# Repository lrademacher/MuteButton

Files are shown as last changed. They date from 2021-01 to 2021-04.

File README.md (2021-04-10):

# MuteButton
A digispark based mute-button for attaching to PC.

See MuteButton for arduino project for the digispark.
See case for 3d models for a case using a LED and a arcade button.

The device looks like this:
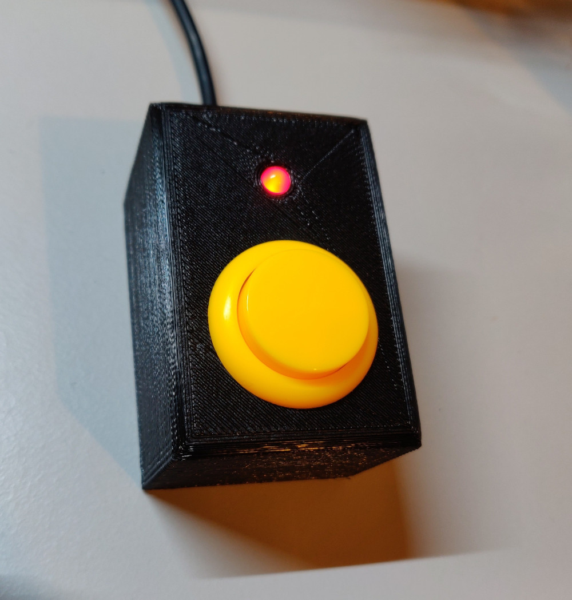
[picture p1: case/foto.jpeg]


## Operation
The device always starts in unmuted state (as there is no backchannel to read the mute information from the system).
When pushing the button, the configured mute command is sent to the PC as keyboard keystroke and the LED is switched on to show that the system is now muted.
When pushing the button again, the configured mute command is sent to the PC as keyboard keystroke and the LED is switched off to show that the system is now unmuted.
In muted state, you can keep the button pushed. On pressing the button, the system is unmuted and on releasing it, it is muted again. The button needs to be pushed for at least 500ms for this "push-to-talk" mode to be activated. The led blinks while this mode is active.

## Links
For a more detailed description see this blog post: https://lars-ra.blogspot.com/2021/04/mute-button-for-conference-calls.html

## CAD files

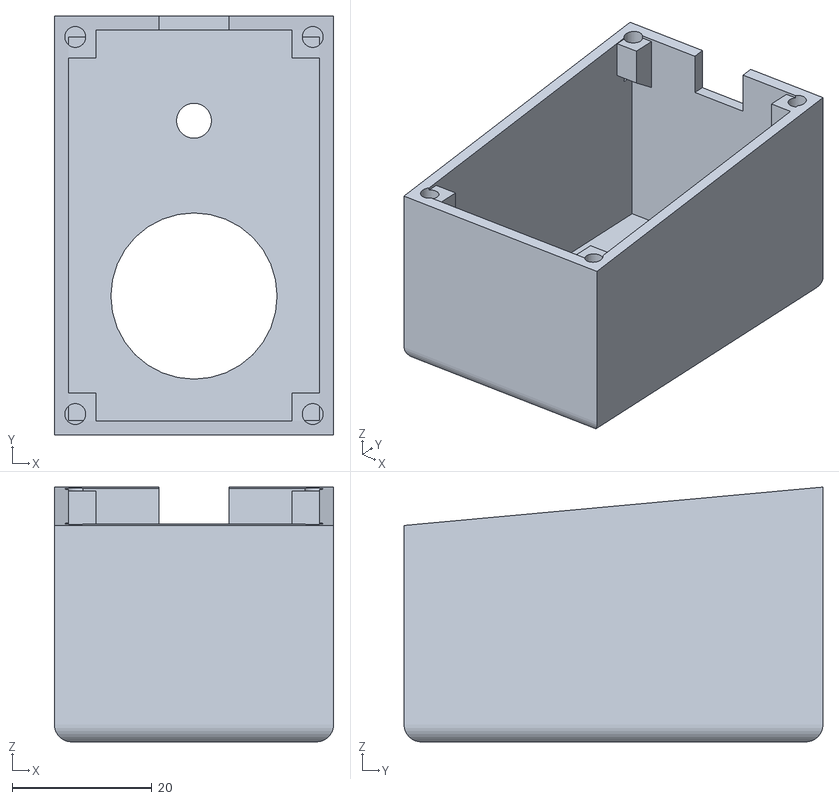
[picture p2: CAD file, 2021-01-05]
case/muteButton.stl
40.0 x 60.0 x 36.5

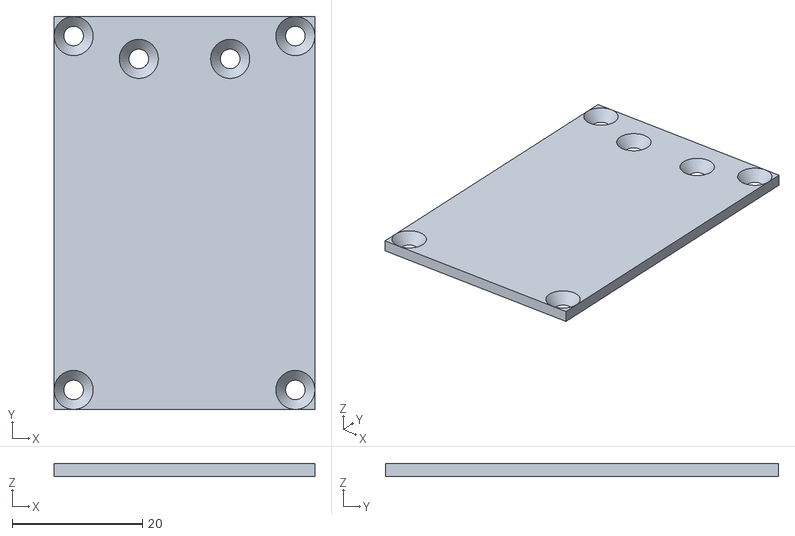
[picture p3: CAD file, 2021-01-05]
case/muteButton_lid_v2.stl
40.0 x 60.3 x 2.00

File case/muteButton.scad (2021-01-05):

// digispark:
// 25x19x4
$fn=32;

t = 2;
h1 = 33 -t;
h2 = 38.5 -t;
l = 60;
w = 40;

button_dia = 23.8;
led_dia = 5;

screw_hole_dia = 3;
screw_hole_dist = 3;
screw_hole_len = 6;

pcb_screw_wall_dist = 3;
pcb_screw_dist = 14;

round_r = 5;

module prism(l, w, h){
   polyhedron(
           points=[[0,0,0], [l,0,0], [l,w,0], [0,w,0], [0,w,h], [l,w,h]],
           faces=[[0,1,2,3],[5,4,3,2],[0,4,5,1],[0,3,4],[5,2,1]]
           );
   }
   
module rounding(r, width) {
    translate([0,-r/2,-r/2])
    difference() {
        cube([width,r,r]);
        translate([0,r,r])
        rotate([0,90,0])
        cylinder(d=r, h=width);
    }
}
   
module case() { 
difference() {
    union() {
        difference() {
            union() {
                cube([w,l,h1]);
                translate([0,0,h1])
                       prism(w,l,  h2-h1);
            }       
            translate([w / 2, button_dia/2 + t + 1 + 5, 0])
                cylinder(h=t, d=button_dia);
            translate([w / 2, 45, 0])
                cylinder(h=t, d=led_dia);
            rounding(round_r, w);
            
            translate([w,l,0])
                rotate([0,0,180])
                    rounding(round_r, w);
            translate([w,0,0])
                rotate([0,0,90])
                    rounding(round_r, l);
            translate([0,l,0])
                rotate([0,0,-90])
                    rounding(round_r, l);
            
            translate([t,t,t])
                cube([w-2*t,l-2*t,h2]);
            
            translate([w/2-10/2,l-t,h2-(5+t)])
                cube([10, t, 5 + t]);
            }
            
        translate([0,0,h1-screw_hole_len]){
            cube([2*screw_hole_dist, 2*screw_hole_dist, screw_hole_len]);
            translate([0,2*screw_hole_dist,0])
            rotate([180,0,0])
            prism(2*screw_hole_dist,2*screw_hole_dist, 4);
        }
        translate([w-2*screw_hole_dist,0,h1-screw_hole_len]){
            cube([2*screw_hole_dist, 2*screw_hole_dist, screw_hole_len]);
            translate([0,2*screw_hole_dist,0])
            rotate([180,0,0])
            prism(2*screw_hole_dist,2*screw_hole_dist, 4);
        }
        translate([0,l-2*screw_hole_dist,h2-screw_hole_len-.6]){
            cube([2*screw_hole_dist, 2*screw_hole_dist, screw_hole_len]);
            translate([2*screw_hole_dist,0,0])
            rotate([180,0,180])
            prism(2*screw_hole_dist,2*screw_hole_dist, 4);
        }
        translate([w-2*screw_hole_dist,l-2*screw_hole_dist,h2-screw_hole_len-.6]){
            cube([2*screw_hole_dist, 2*screw_hole_dist, screw_hole_len]);
                        translate([2*screw_hole_dist,0,0])
            rotate([180,0,180])
            prism(2*screw_hole_dist,2*screw_hole_dist, 4);
        }
    }
    actual_screw_hole_len = screw_hole_len + 3;
    translate([screw_hole_dist,screw_hole_dist,h1-actual_screw_hole_len+.4])
        cylinder(d=screw_hole_dia, h=actual_screw_hole_len + 3);
    
    translate([w-screw_hole_dist,screw_hole_dist,h1-actual_screw_hole_len+.4])
        cylinder(d=screw_hole_dia, h=actual_screw_hole_len);
        
    translate([screw_hole_dist,l-screw_hole_dist,h2-actual_screw_hole_len+.4])
        cylinder(d=screw_hole_dia, h=actual_screw_hole_len);
        
    translate([w-screw_hole_dist,l-screw_hole_dist,h2-actual_screw_hole_len+.4])
        cylinder(d=screw_hole_dia, h=actual_screw_hole_len);
}
}

module lid() {
    l2 = sqrt(pow(l, 2) + pow(h2-h1, 2));
    
    difference(){
        cube([w,l2,t]);
        
        translate([screw_hole_dist,screw_hole_dist,0])
        cylinder(d1=screw_hole_dia, d2=screw_hole_dia*2, h=t);
        
        translate([w-screw_hole_dist,screw_hole_dist,0])
        cylinder(d1=screw_hole_dia, d2=screw_hole_dia*2, h=t);
        
        translate([screw_hole_dist,l2-screw_hole_dist,0])
        cylinder(d1=screw_hole_dia, d2=screw_hole_dia*2, h=t);
        
        translate([w-screw_hole_dist,l2-screw_hole_dist,0])
        cylinder(d1=screw_hole_dia, d2=screw_hole_dia*2, h=t);
        
        translate([w / 2 + pcb_screw_dist / 2, l2 - t - screw_hole_dia / 2 - pcb_screw_wall_dist, 0])
        cylinder(d1=screw_hole_dia, d2=screw_hole_dia*2, h=t);
        
        translate([w / 2 - pcb_screw_dist / 2, l2 - t - screw_hole_dia / 2 - pcb_screw_wall_dist, 0])
        cylinder(d1=screw_hole_dia, d2=screw_hole_dia*2, h=t);
    }
}

//case();

/*translate([0,0,h1])
rotate([atan((h2-h1)/l),0,0])*/
lid();

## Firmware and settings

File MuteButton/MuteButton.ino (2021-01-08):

/* Includes */
#include "DigiKeyboard.h"

/* Defines */
#define LED_PIN (0)
#define BUTTON_PIN (2)
#define BUTTON_DEBOUNCE_DELAY (50)

#define KEY_OE 0xBB

/* Types */
enum LedState {
  LED_ON,
  LED_OFF,
  LED_TOGGLE_SLOW = 500,
  LED_TOGGLE_FAST = 200
};

enum ButtonState {
  BUTTON_PRESSED,
  BUTTON_LONG_PRESSED = 500,
  BUTTON_RELEASED
};

struct locals {
  bool muted;
  
  LedState ledState;
  ButtonState buttonState;
  ButtonState lastButtonState;

  unsigned long lastLedToggle;

  int lastButtonReading;
  unsigned long lastDebounceTime;
};

/* Variables */
static struct locals l;

/* Prototypes */
static void handleLed();
static void debounceButton();
static void handleButton();

/* Implementations */
void setup() {
  l.ledState = LED_OFF;
  l.buttonState = l.lastButtonState = BUTTON_RELEASED;
  l.lastButtonReading = LOW;

  pinMode(LED_PIN, OUTPUT);
  pinMode(BUTTON_PIN, INPUT_PULLUP);

  // this is generally not necessary but with some older systems it seems to
  // prevent missing the first character after a delay:
  DigiKeyboard.sendKeyStroke(0);
}

void loop() {
  handleLed();
  debounceButton();
  handleButton();
}

static void handleLed() {
  switch (l.ledState)
  {
    case LED_OFF:
      digitalWrite(LED_PIN, HIGH);
      break;
    case LED_ON:
      digitalWrite(LED_PIN, LOW);
      break;
    case LED_TOGGLE_SLOW:
    case LED_TOGGLE_FAST:
      if ((millis() - l.lastLedToggle) > l.ledState) {
        digitalWrite(LED_PIN, !digitalRead(LED_PIN));
        l.lastLedToggle = millis();
      }
      break;
  }
}

static void debounceButton() {
  int reading = digitalRead(BUTTON_PIN);

  if (reading != l.lastButtonReading)
  {
    // reset the debouncing timer
    l.lastDebounceTime = millis();
  }

  if ((millis() - l.lastDebounceTime) > BUTTON_DEBOUNCE_DELAY) {
    if (reading == LOW) {
      l.buttonState = BUTTON_PRESSED;
      if ((millis() - l.lastDebounceTime) > BUTTON_LONG_PRESSED) {
        l.buttonState = BUTTON_LONG_PRESSED;
      }
    } else  if (reading == HIGH) {
      l.buttonState = BUTTON_RELEASED;
    }
  }

  // save the reading. Next time through the loop, it'll be the lastButtonReading:
  l.lastButtonReading = reading;
}

static void handleButton() {
  if(l.buttonState != l.lastButtonState)
  {
    if (l.buttonState == BUTTON_PRESSED)
    {
      // toggle mute state
      mute(!l.muted);
      l.ledState = l.muted ? LED_ON : LED_OFF;
    }
    else if (l.buttonState == BUTTON_LONG_PRESSED)
    {
      if(!l.muted)
      {
        // push-to-talk detected  
        l.ledState = LED_TOGGLE_FAST;
      }
    }
    else if (l.buttonState == BUTTON_RELEASED)
    {
      if(l.lastButtonState == BUTTON_LONG_PRESSED && !l.muted)
      {
        // finished push-to-talk
        mute(true);
        l.ledState = LED_ON;
      }
    }

    l.lastButtonState = l.buttonState;
  }
}


static void mute(bool activate) {
  l.muted = activate;

  DigiKeyboard.sendKeyStroke(KEY_F12, MOD_CONTROL_LEFT);
}

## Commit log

2021-01-05 rudimentary showcase for button and led
2021-01-05 basically works fine. Missing:
    [MuteButton.ino]
2021-01-05 Added case files
    [muteButton.scad, muteButton.stl, muteButton_lid_v2.stl]
2021-01-05 Reduced debounce delay for quick button click reaction
2021-01-08 Decreased push-to-talk button press duration to 500ms
